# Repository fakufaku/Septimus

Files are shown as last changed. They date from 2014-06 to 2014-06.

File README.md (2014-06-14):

Septimus
========

[Septimus](https://en.wikipedia.org/wiki/Septimus_%28praenomen%29) is a driver
board to control large (2.3 inches) seven segments displays. It is designed for four
characters and has its own step-up converter to produce the large voltage
needed by the large seven segments displays.

The display is controlled by an ATtiny2313. The display is controlled through
the two-wire interface of the microcontroller.

All the components are commonly available discrete through-hole parts.

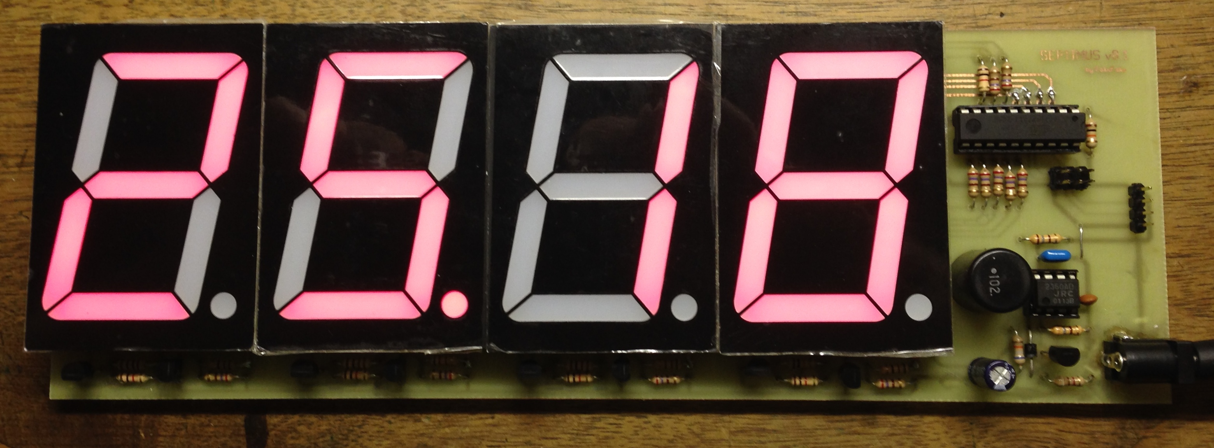
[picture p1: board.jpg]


Because of the size of the 7-segments, I couldn't use the free version of Eagle
CAD and decided to take the chance to learn its free alternative, the [gEDA suite](http://geda-project.org/).  
I found this [tutorial](http://wiki.geda-project.org/geda:gsch2pcb_tutorial)
particularly useful in my learning process. The combo of gschem/pcb is quite
powerful and has a simplicity that Eagle CAD lacks. However, the workflow to go
from schematics to PCB and keep consistency is very cumbersome and error prone.
Making custom parts is also not very practical. As a conclusion, it was a good
experience and is definitely an advantage to know an EDA without the
limitations of Eagle CAD with respect to board size and multiple layers, but I
will stick to Eagle for my simple projects.

Bill of material
----------------

* ATtiny2313 (DIP20)
* NJM2360AD Voltage regulator (drop-in replacement of [MC34063A](http://www.ti.com/litv/slls636m))
* 6x NPN transistors (C1815, ECB) (Q101, Q201, Q203, Q205, Q207, Q209)
* 4x PNP transistors (A1015, ECB) (Q202, Q204, Q206, Q208)
* 1x 1000uH coil (300mil pin spacing)
* 5x 1K resistor (R202, R206, R210, R214, R312)
* 7x 10K resistor (R201, R205, R209, R213, R301, R310, R311)
* 11x 270 resistor (R204, R208, R212, R126, R302, R303, R304, R305, R306, R307, R308)
* 4x 51 resistor (R203, R207, R211, R215)
* 3x 180 resistor (R101, R104, R309)
* 1x 9.1K resistor (R102)
* 1x 68K resistor (R103)
* 1x 10uF cap ceramic (C101)
* 1x 100uF cap electrolytic (C102)
* 1x 1nF cap ceramic (C103)
* 1x 0.1uF cap ceramic (C104)
* 1x diode (schottky, 40V)
* 1x ISP header (small footprint, 2x3 pins)
* 1x 1x4 straight pin header (100mil spacing)
* 4x 2.3inch 7-segments displays
* 1x 2.1mm barrel jack

Etch the board
--------------

The top and bottom mask files are `Septimus_mask_top.pdf` and `Septimus_mask_bot.pdf`,
respectively. The mask are mirrored so that the printed side goes directly onto the copper.
There are alignment marks and some text to avoid mistakes.

The board is double-sided and thus not trivial for home etching. However, there are only 
four tracks on the top layer and it is thus conceivable to make the PCB single layer
and manually patch it with four wires.

In addition, because of the difficulty of making metallized holes at home, a number
of jumper wires are required (7) as shown on `Septimus_info.pdf`. In the same file,
the drill bits sizes are described.

Alternatively, the gerber files are available in the folder `gerber` for sending
to a board house.

Firmware
--------

The firmware can be burnt using an ISP programmer (such as the usbtiny).

    cd firmware/
    make avrdude

If you do not use the usbtiny, edit the Makefile `PROGRAMMER` variable to
reflect the device you use.

The fuse settings are left to factory default (Low:0x64, High:0xDF, Ext:0xFF).

Arduino library
---------------

### Install

Copy `SeptimusLib/` into your local Arduino `libraries` folder. Restart
the Arduino IDE and try one of the examples.

### Example sketch.

    #include <Wire.h>
    #include <Septimus.h>

    Septimus display = Septimus(SLAVE_ADDRESS);

    unsigned int counter = 0;

    void setup() {
      display.begin();
    }

    void loop() {
      // print current counter value
      display.print(counter, DEC);
      display.writeDisplay();

      // increment and wait a second
      counter++;
      delay(1000);
    }

### Adjust brightness of display

It is possible to set the brightness of the display by using

    display.setBrightness(b)

where `b` is a value between 0 (dimmest) to 255 (brightest).

### Adjust blinking rate of display

The seven segment works by displaying each digit individually
but at high frequency so that we have the illusion of seeing
all digit lit up simultaneously. The blinking rate can be
changed using the following code. The same command can be used
to switch off the display.

    display.setRate(RATE_488Hz) // 488 Hz (default)
    display.setRate(RATE_4kHz)  // 4 kHz
    display.setRate(RATE_61Hz)  // 61 Hz
    display.setRate(RATE_STOP)  // display is off

Note that the only rate that gives smooth display and
allows for adjusting the brightness is 488 Hz, the default.

At 4kHz, the display is somewhat brighter, but only works
with brightness set to 255.

License
-------

### Schematics, PCB, firmware

(c) 2014, Robin Scheibler aka FakuFaku

    "THE BEER-WARE LICENSE" (Revision 42):
    <fakufaku@gmail.com> wrote this file. As long as you retain this notice you
    can do whatever you want with this stuff. If we meet some day, and you think
    this stuff is worth it, you can buy me a beer in return -- Robin Scheibler



With the exception of the USI TWI Slave driver code by Donald R. Blake which is GPL.

### Arduino library

The arduino library was adapted from the excellent [Adafruit LED
Backpack](https://github.com/adafruit/Adafruit-LED-Backpack-Library) library
which is released under MIT or BSD license, depending on where you look.

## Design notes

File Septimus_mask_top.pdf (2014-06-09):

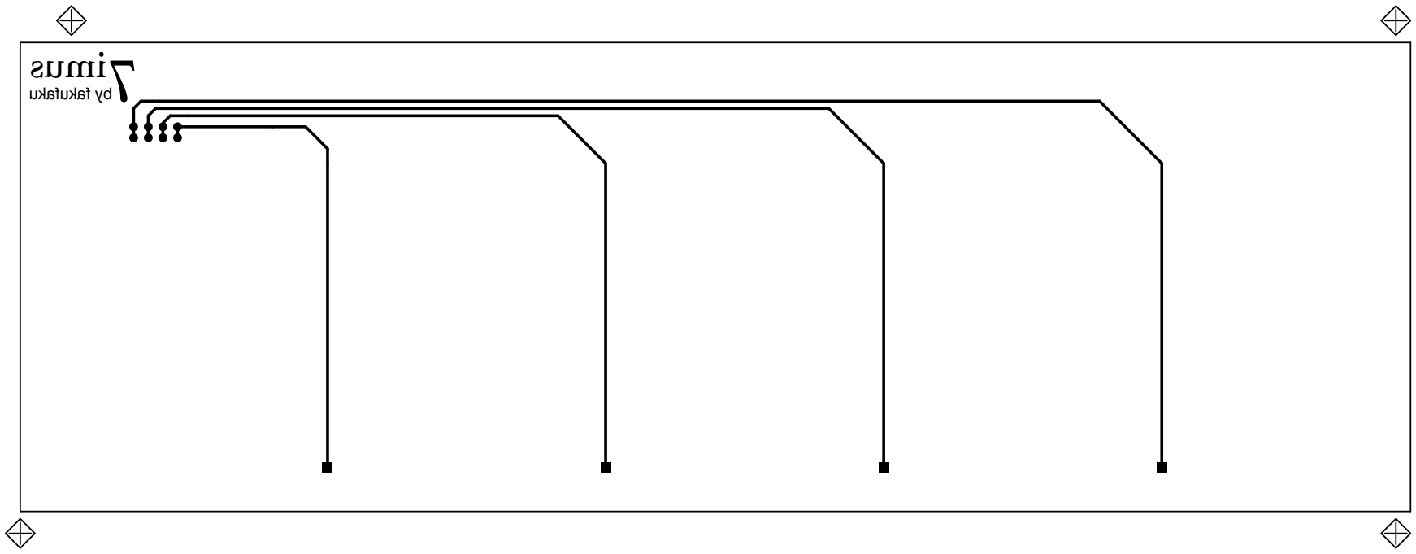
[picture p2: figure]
7imus by fakufaku

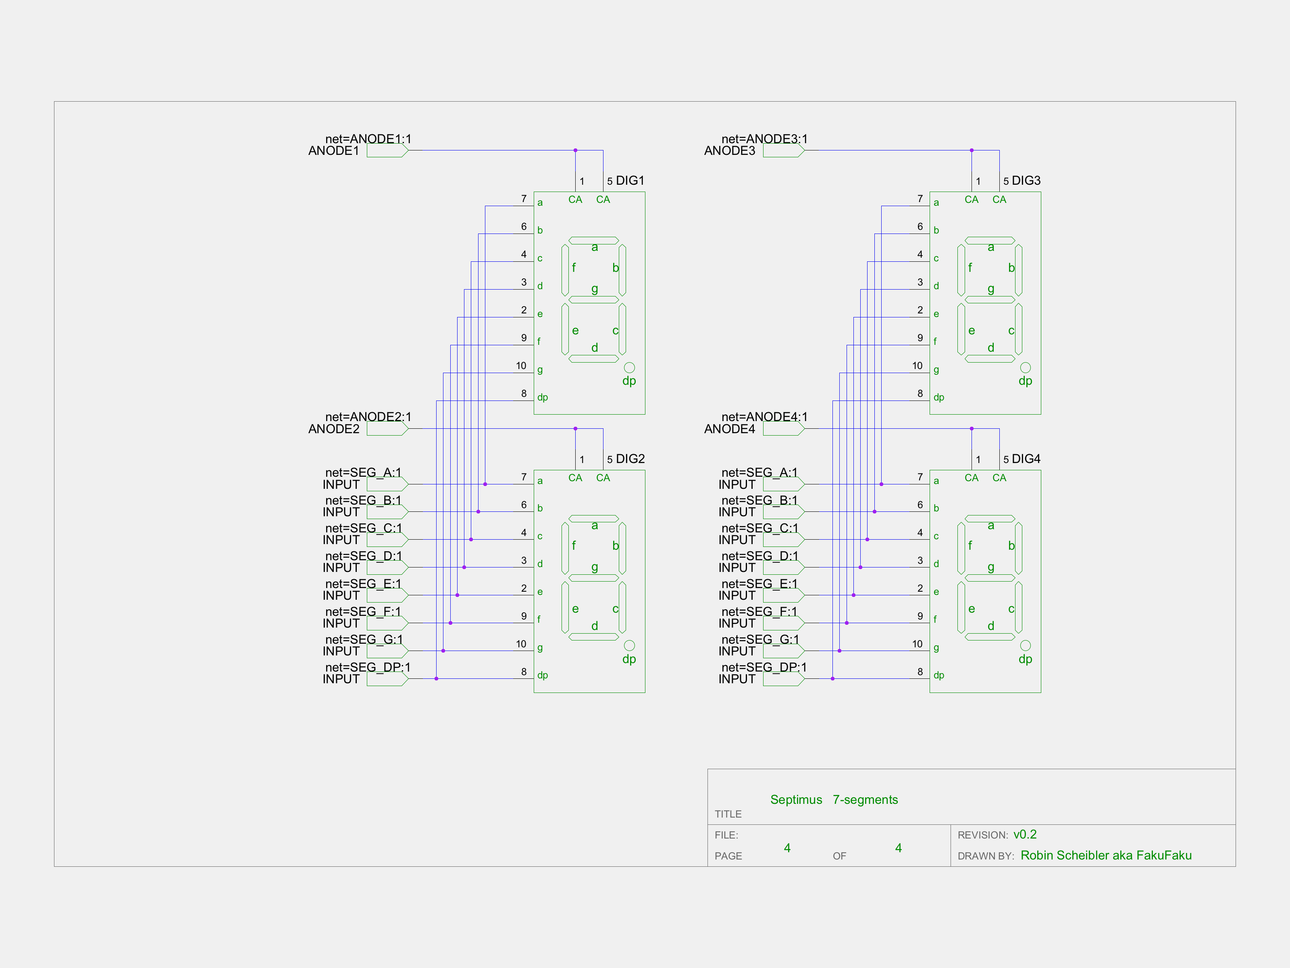
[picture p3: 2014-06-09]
schematics/Septimus_4_display.png

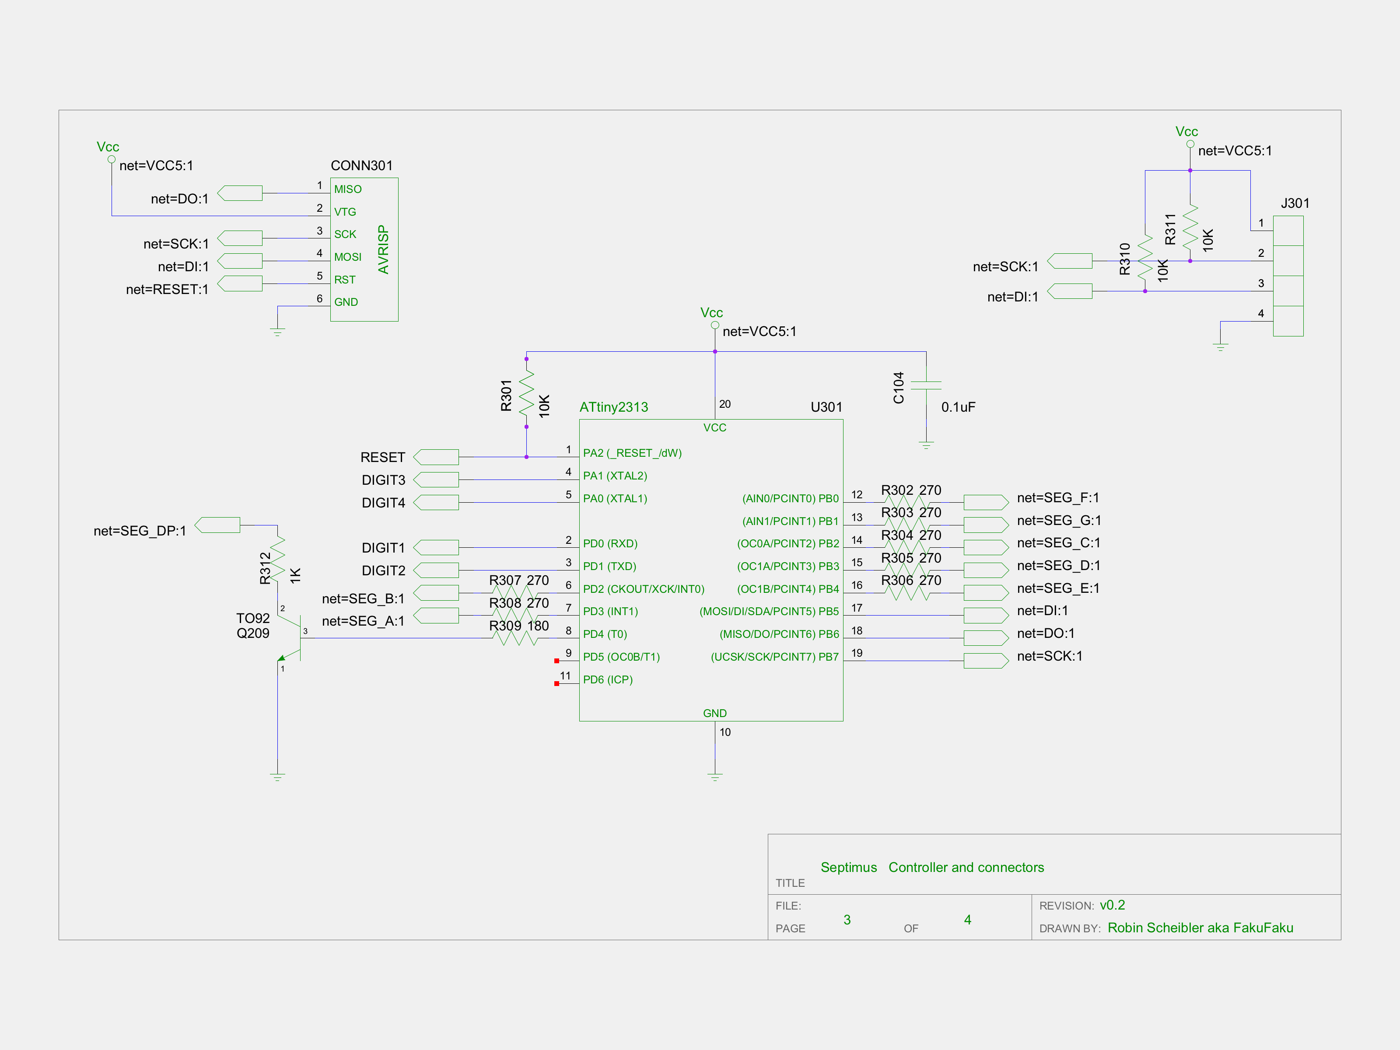
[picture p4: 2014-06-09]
schematics/Septimus_3_controller.png

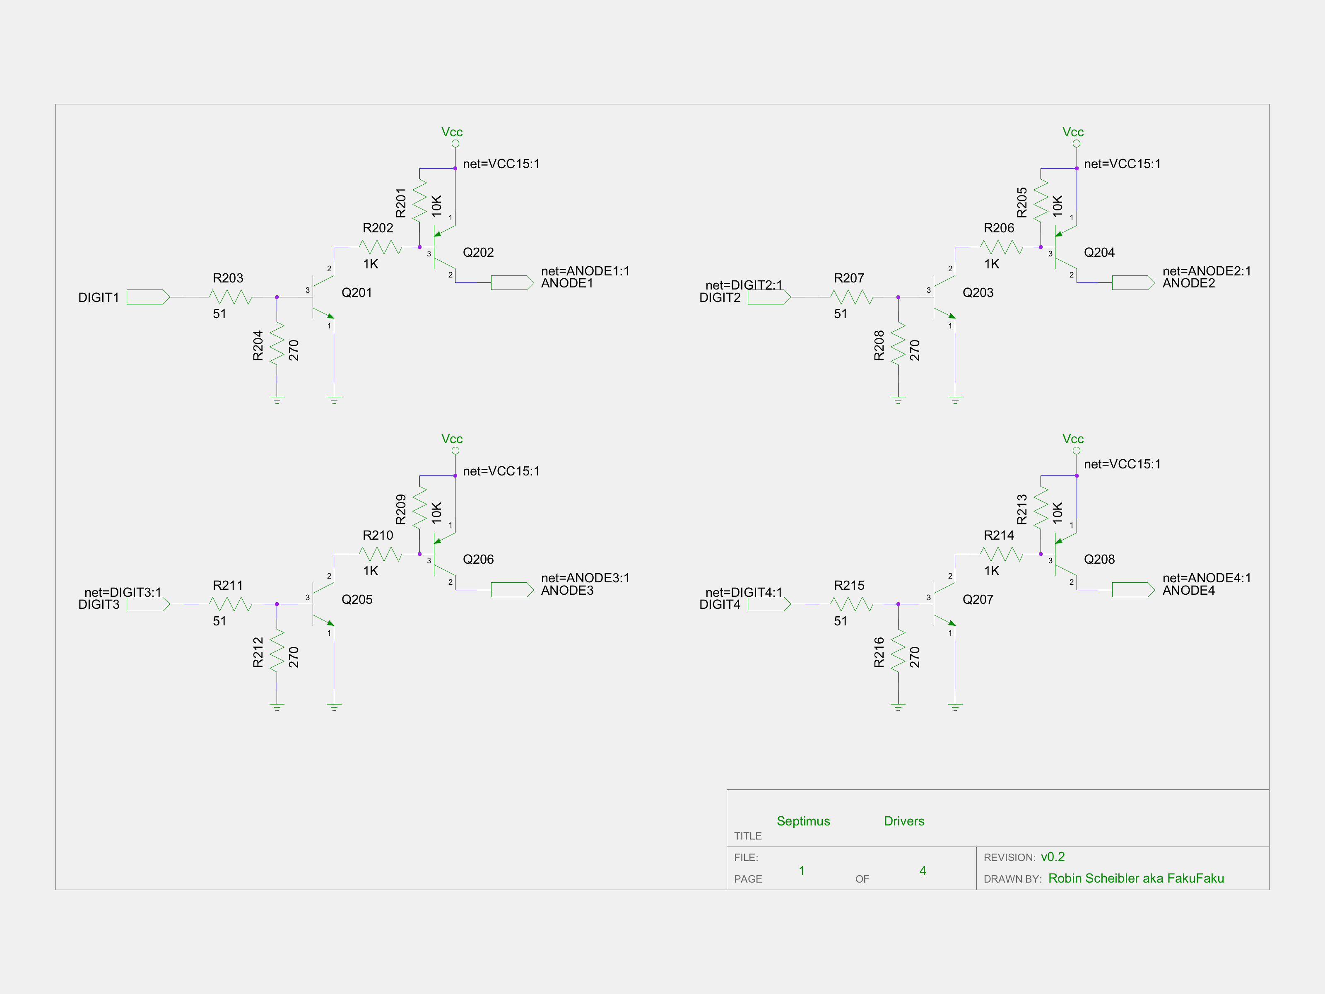
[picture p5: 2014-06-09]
schematics/Septimus_1_drivers.png

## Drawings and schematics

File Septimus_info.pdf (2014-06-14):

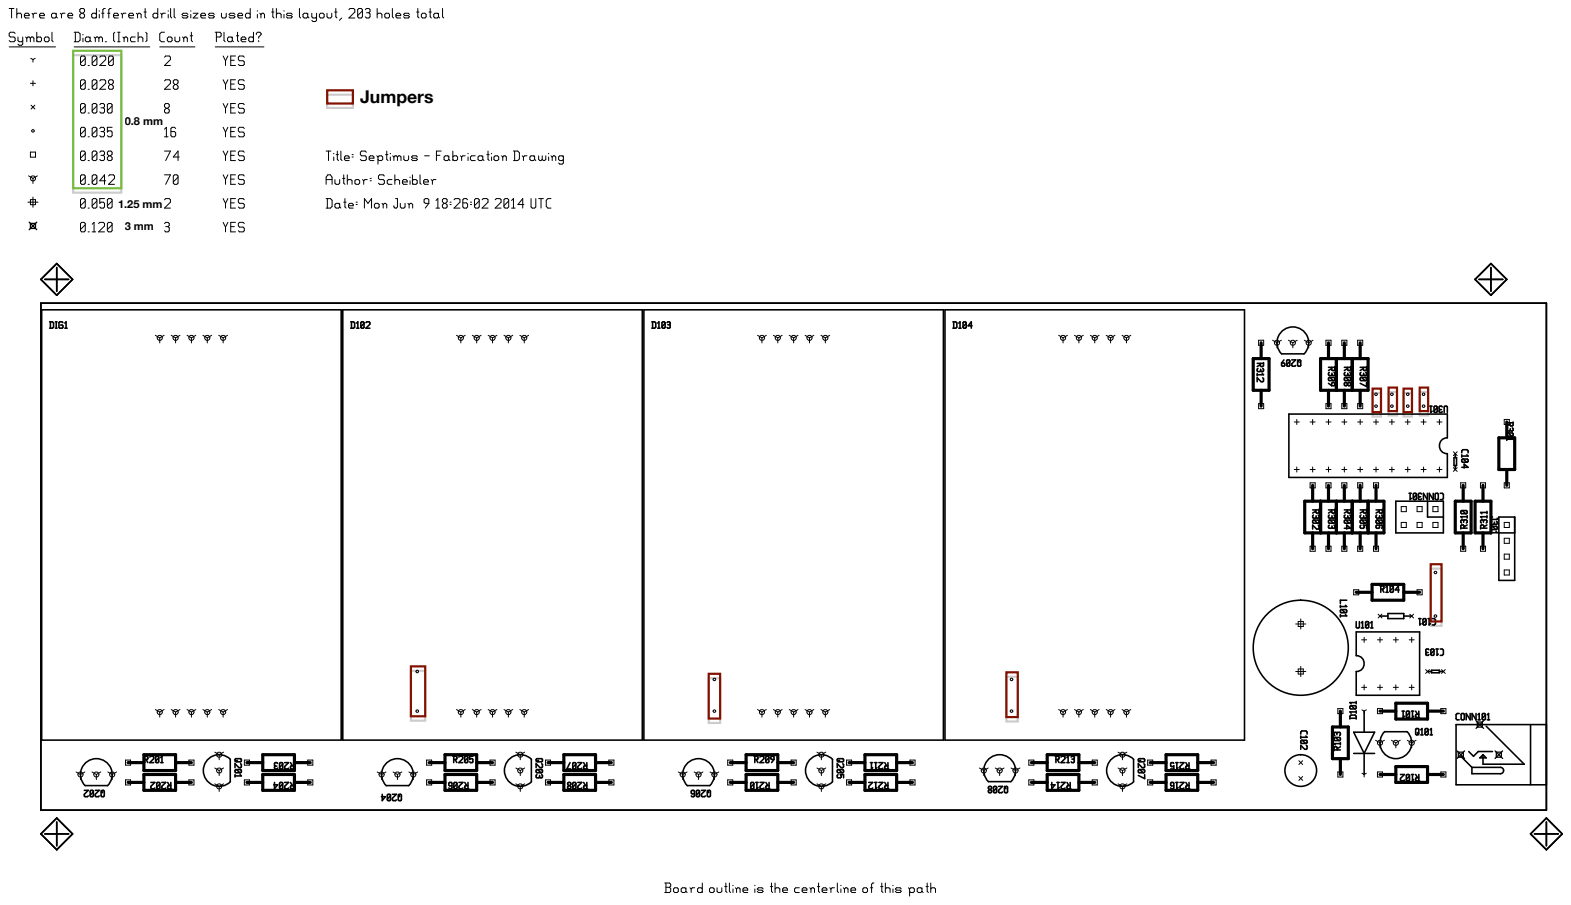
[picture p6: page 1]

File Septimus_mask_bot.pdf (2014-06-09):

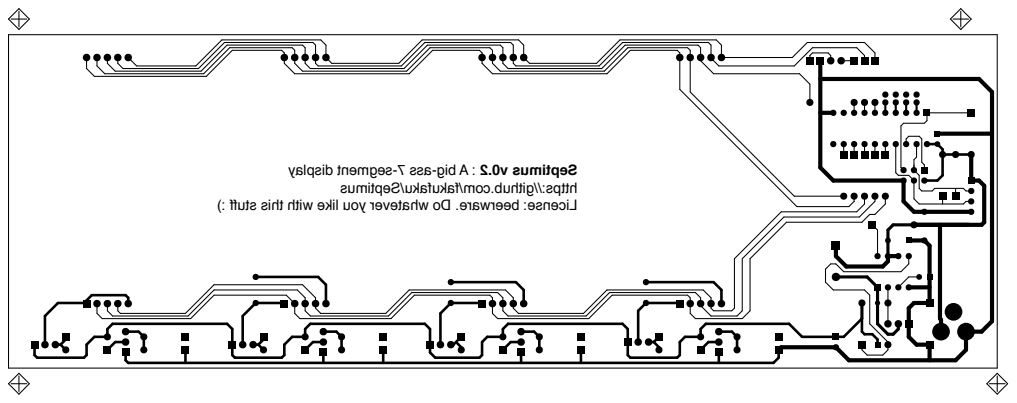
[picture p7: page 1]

: A big-ass 7-segment display Septimus v0.2

https://github.com/fakufaku/Septimus

License: beerware. Do whatever you like with this stuff :)

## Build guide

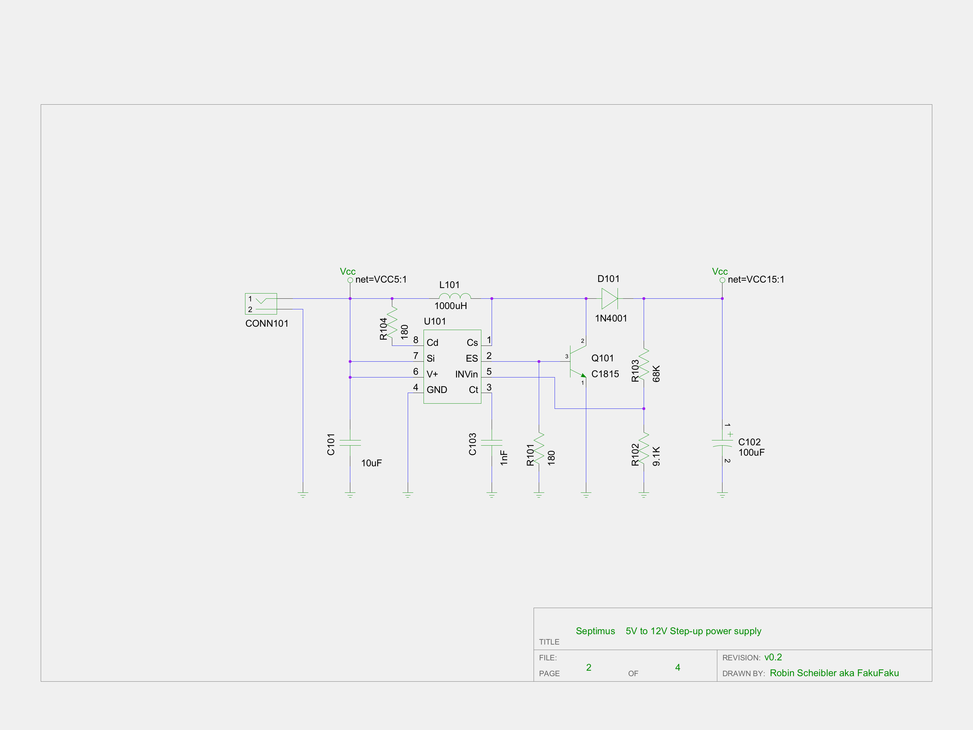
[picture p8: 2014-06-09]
schematics/Septimus_2_step-up.png

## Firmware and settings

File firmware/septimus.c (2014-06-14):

/*
* ----------------------------------------------------------------------------
* "THE BEER-WARE LICENSE" (Revision 42):
* <fakufaku@gmail.com> wrote this file. As long as you retain this notice you
* can do whatever you want with this stuff. If we meet some day, and you think
* this stuff is worth it, you can buy me a beer in return -- Robin Scheibler
* ----------------------------------------------------------------------------
*/

/*
 * This is the firmware of the Septimus big 7 segment display.
 * All code and schematics available online
 * https://github.com/fakufaku/Septimus
 */

#include <avr/sleep.h>
#include <avr/io.h>
#include <avr/interrupt.h>

#include <stdlib.h>

#include "usiTwiSlave.h"

// Allows to disable interrupt in some parts of the code
#define ENTER_CRIT()    {char volatile saved_sreg = SREG; cli()
#define LEAVE_CRIT()    SREG = saved_sreg;}

// the different timer0 frequencies
#define TIMER0_CLKDIV_4kHz (1 << CS00)
#define TIMER0_CLKDIV_488Hz (1 << CS01)
#define TIMER0_CLKDIV_61Hz (1 << CS01) | (1 << CS00)
#define TIMER0_CLKDIV_15Hz (1 << CS02)
#define TIMER0_CLKDIV_4Hz (1 << CS02) | (1 << CS00)

// The different interrupts to enable
#define SET_OCR0A_INT() TIMSK |= (1 << OCIE0A)
#define UNSET_OCR0A_INT() TIMSK &= ~(1 << OCIE0A)
#define TIMER0_STOP() TCCR0B = 0
#define TIMER0_SET_RATE(R) TCCR0B = R

#define FIRMWARE_REVISION 1
#define SLAVE_ADDRESS 50

#define DIGIT_NUMBER 4

#define DEFAULT_BRIGHTNESS 0xFE

// the bit buffer
uint8_t buffer[4] = {0x0, 0x0, 0x0, 0x0};

// we use a timer to rotate the digits
uint8_t digit_counter = 0;

// brightness register
uint8_t brightness = DEFAULT_BRIGHTNESS;

// TWI commands
#define CMD_01_SEGMENTS 0x01
#define CMD_02_BRIGHTNESS 0x02
#define CMD_03_RATE 0x03

// define the digits pins
#define DIG4_PORT PORTD
#define DIG4_DDR  DDRD
#define DIG4_PIN  0

#define DIG3_PORT PORTD
#define DIG3_DDR  DDRD
#define DIG3_PIN  1

#define DIG2_PORT PORTA
#define DIG2_DDR  DDRA
#define DIG2_PIN  1

#define DIG1_PORT PORTA
#define DIG1_DDR  DDRA
#define DIG1_PIN  0

// define the segments pins
#define SEG_A_PORT PORTD
#define SEG_A_DDR  DDRD
#define SEG_A_PIN  3

#define SEG_B_PORT PORTD
#define SEG_B_DDR  DDRD
#define SEG_B_PIN  2

#define SEG_C_PORT PORTB
#define SEG_C_DDR  DDRB
#define SEG_C_PIN  2

#define SEG_D_PORT PORTB
#define SEG_D_DDR  DDRB
#define SEG_D_PIN  3

#define SEG_E_PORT PORTB
#define SEG_E_DDR  DDRB
#define SEG_E_PIN  4

#define SEG_F_PORT PORTB
#define SEG_F_DDR  DDRB
#define SEG_F_PIN  0

#define SEG_G_PORT PORTB
#define SEG_G_DDR  DDRB
#define SEG_G_PIN  1

#define SEG_DP_PORT PORTD
#define SEG_DP_DDR  DDRD
#define SEG_DP_PIN  4

// turn off all digits
void digits_all_off(void)
{
  DIG1_PORT &= ~_BV(DIG1_PIN);
  DIG2_PORT &= ~_BV(DIG2_PIN);
  DIG3_PORT &= ~_BV(DIG3_PIN);
  DIG4_PORT &= ~_BV(DIG4_PIN);
}

// light up a digit
void light_digit(uint8_t n)
{
  switch (n)
  {
    case 1:
      DIG1_PORT |= _BV(DIG1_PIN);
      break;

    case 2:
      DIG2_PORT |= _BV(DIG2_PIN);
      break;

    case 3:
      DIG3_PORT |= _BV(DIG3_PIN);
      break;

    case 4:
      DIG4_PORT |= _BV(DIG4_PIN);
      break;

    default:
      digits_all_off();
  }
}

// set the segments for a given number
void set_segments(uint8_t bits)
{
  //A
  if (bits & 0x1)
    SEG_A_DDR |= _BV(SEG_A_PIN);
  else
    SEG_A_DDR &= ~_BV(SEG_A_PIN);
  //B
  if (bits & 0x2)
    SEG_B_DDR |= _BV(SEG_B_PIN);
  else
    SEG_B_DDR &= ~_BV(SEG_B_PIN);
  //C
  if (bits & 0x4)
    SEG_C_DDR |= _BV(SEG_C_PIN);
  else
    SEG_C_DDR &= ~_BV(SEG_C_PIN);
  //D
  if (bits & 0x8)
    SEG_D_DDR |= _BV(SEG_D_PIN);
  else
    SEG_D_DDR &= ~_BV(SEG_D_PIN);
  //E
  if (bits & 0x10)
    SEG_E_DDR |= _BV(SEG_E_PIN);
  else
    SEG_E_DDR &= ~_BV(SEG_E_PIN);
  //F
  if (bits & 0x20)
    SEG_F_DDR |= _BV(SEG_F_PIN);
  else
    SEG_F_DDR &= ~_BV(SEG_F_PIN);
  //G
  if (bits & 0x40)
    SEG_G_DDR |= _BV(SEG_G_PIN);
  else
    SEG_G_DDR &= ~_BV(SEG_G_PIN);
  //DP
  if (bits & 0x80)
  {
    SEG_DP_DDR |= _BV(SEG_DP_PIN);
    SEG_DP_PORT |= _BV(SEG_DP_PIN);
  }
  else
  {
    SEG_DP_DDR |= _BV(SEG_DP_PIN);
    SEG_DP_PORT &= ~_BV(SEG_DP_PIN);
  }
}

// process the TWI command
void processTWI( void )
{
  uint8_t b,c;

  // receive the command
  b = usiTwiReceiveByte();

  switch (b) {
    case CMD_01_SEGMENTS: // save brightness
      // receive the 4 digits
      for (c = 0 ; c < DIGIT_NUMBER ; c++)
        buffer[c] = usiTwiReceiveByte();
      break;

    case CMD_02_BRIGHTNESS:
      // receive the brightness byte
      brightness = usiTwiReceiveByte();  // update the output compare A with new value
      if (brightness == 0xFF)
        UNSET_OCR0A_INT();
      else
        SET_OCR0A_INT();
      break;

    case CMD_03_RATE:
      c = usiTwiReceiveByte();
      switch (c)
      {
        case 0x00:
          TIMER0_STOP();
          break;

        case 0x01:
          TIMER0_SET_RATE(TIMER0_CLKDIV_4kHz);
          break;

        case 0x02:
          TIMER0_SET_RATE(TIMER0_CLKDIV_488Hz);
          break;

        case 0x03:
          TIMER0_SET_RATE(TIMER0_CLKDIV_61Hz);
          break;
      }
      break;

    default:
      // nothing to do
      break;
  }
}

// The output compare A interrupt to turn off the digit
SIGNAL(TIMER0_COMPA_vect)
{
  ENTER_CRIT();

  // turn off all digits
  digits_all_off();

  LEAVE_CRIT();
}

// The timer overflow interrupt routine
SIGNAL(TIMER0_OVF_vect)
{
  ENTER_CRIT();

  // turn off all digits
  digits_all_off();

  // increment the digit to display
  digit_counter = (digit_counter+1) % DIGIT_NUMBER;

  // set the segments
  set_segments(buffer[digit_counter]);

  // turn digit on
  light_digit(digit_counter+1);

  // set the time the digit should light up
  OCR0A = brightness;

  LEAVE_CRIT();
}

int main()
{
  // set digits as output and disable them all
  DIG1_DDR |= _BV(DIG1_PIN);
  DIG2_DDR |= _BV(DIG2_PIN);
  DIG3_DDR |= _BV(DIG3_PIN);
  DIG4_DDR |= _BV(DIG4_PIN);
  light_digit(0);

  // setup all segments as inputs and low
  SEG_A_DDR &= ~_BV(SEG_A_PIN);
  SEG_B_DDR &= ~_BV(SEG_B_PIN);
  SEG_C_DDR &= ~_BV(SEG_C_PIN);
  SEG_D_DDR &= ~_BV(SEG_D_PIN);
  SEG_E_DDR &= ~_BV(SEG_E_PIN);
  SEG_F_DDR &= ~_BV(SEG_F_PIN);
  SEG_G_DDR &= ~_BV(SEG_G_PIN);
  
  SEG_A_PORT &= ~_BV(SEG_A_PIN);
  SEG_B_PORT &= ~_BV(SEG_B_PIN);
  SEG_C_PORT &= ~_BV(SEG_C_PIN);
  SEG_D_PORT &= ~_BV(SEG_D_PIN);
  SEG_E_PORT &= ~_BV(SEG_E_PIN);
  SEG_F_PORT &= ~_BV(SEG_F_PIN);
  SEG_G_PORT &= ~_BV(SEG_G_PIN);

  // set DP as output and to ground
  SEG_DP_DDR |= _BV(SEG_DP_PIN);
  SEG_DP_PORT &= ~_BV(SEG_DP_PIN);

  // set up timer 1 as system clock
  TIMSK = (1 << TOIE0);         // overflow interrupts
  TCCR0B = TIMER0_CLKDIV_488Hz; // default blink rate at 488Hz

  
  // init the TWI slave
  usiTwiSlaveInit(SLAVE_ADDRESS);

  // enable interrupts
  sei();

  // The infinite loop
  while (1)
  {
    // process Twi commands
    while (usiTwiDataInReceiveBuffer())
    {
      processTWI();
    }
  }

}

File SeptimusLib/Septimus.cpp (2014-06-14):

/***************************************************
 * This is the library for I2C big 7 segment display 'Septimus'
 *
 * This library was adapted from adafruit's i2c matrix led backpack
 * library. It was slimmed down and adapted to work with this
 * custom 7 segment back pack 'Septimus'
 * ----> https://github.com/fakufaku/Septimus
 *
 * Septimus uses I2C to communicate, 2 pins are required to interface. 
 * The I2C address of the display is 50 (decimal)
 *
 * Originally written by Limor Fried/Ladyada for Adafruit Industries.
 * Adapted for Septimus by Robin Scheibler/fakufaku
 * BSD license, all text above must be included in any redistribution
 * ****************************************************/

#ifdef __AVR_ATtiny85__
#include <TinyWireM.h>
#define Wire TinyWireM
#else
#include <Wire.h>
#endif

#include "Septimus.h"

static const uint8_t numbertable[] = {
  0x3F, /* 0 */
  0x06, /* 1 */
  0x5B, /* 2 */
  0x4F, /* 3 */
  0x66, /* 4 */
  0x6D, /* 5 */
  0x7D, /* 6 */
  0x07, /* 7 */
  0x7F, /* 8 */
  0x6F, /* 9 */
  0x77, /* a */
  0x7C, /* b */
  0x39, /* C */
  0x5E, /* d */
  0x79, /* E */
  0x71, /* F */
};

void Septimus::setBrightness(uint8_t b) 
{
  Wire.beginTransmission(i2c_addr);
  Wire.write(CMD_02_BRIGHTNESS);
  Wire.write(b);
  Wire.endTransmission();
}

Septimus::Septimus(uint8_t _addr = SLAVE_ADDRESS) 
{
  i2c_addr = _addr;
  position = 0;
}

void Septimus::begin(void)
{
  Wire.begin();
  setRate(RATE_488Hz);
  setBrightness(255);
}

void Septimus::writeDisplay(void) 
{
  Wire.beginTransmission(i2c_addr);
  Wire.write(CMD_01_SEGMENTS);
  for (uint8_t i = 0; i < DIGIT_NUMBER; i++)
  {
    Wire.write(displaybuffer[DIGIT_NUMBER-i-1]);
  }
  Wire.endTransmission();
}

void Septimus::setRate(uint8_t r)
{
  Wire.beginTransmission(i2c_addr);
  Wire.write(CMD_03_RATE);
  uint8_t v = Wire.write(r);
  Wire.endTransmission();
}

void Septimus::clear(void) 
{
  for (uint8_t i = 0; i < DIGIT_NUMBER; i++) {
    displaybuffer[i] = 0;
  }
}

void Septimus::print(unsigned long n, int base)
{
  if (base == 0) write(n);
  else printNumber(n, base);
}

void Septimus::print(char c, int base)
{
  print((long) c, base);
}

void Septimus::print(unsigned char b, int base)
{
  print((unsigned long) b, base);
}

void Septimus::print(int n, int base)
{
  print((long) n, base);
}

void Septimus::print(unsigned int n, int base)
{
  print((unsigned long) n, base);
}

void Septimus::println(void) 
{
  position = 0;
}

void Septimus::println(char c, int base)
{
  print(c, base);
  println();
}

void Septimus::println(unsigned char b, int base)
{
  print(b, base);
  println();
}

void Septimus::println(int n, int base)
{
  print(n, base);
  println();
}

void Septimus::println(unsigned int n, int base)
{
  print(n, base);
  println();
}

void Septimus::println(long n, int base)
{
  print(n, base);
  println();
}

void Septimus::println(unsigned long n, int base)
{
  print(n, base);
  println();
}

void Septimus::println(double n, int digits)
{
  print(n, digits);
  println();
}

void Septimus::print(double n, int digits)
{
  printFloat(n, digits);
}


size_t Septimus::write(uint8_t c) 
{

  uint8_t r = 0;

  if (c == '\n') position = 0;
  if (c == '\r') position = 0;

  if ((c >= '0') && (c <= '9')) {
    writeDigitNum(position, c-'0');
    r = 1;
  }

  position++;

  return r;
}

void Septimus::writeDigitRaw(uint8_t d, uint8_t bitmask) 
{
  if (d >= 4) return;
  displaybuffer[d] = bitmask;
}

void Septimus::writeDigitNum(uint8_t d, uint8_t num, boolean dot) 
{
  if (d >= 4) return;

  writeDigitRaw(d, numbertable[num] | (dot << 7));
}

void Septimus::print(long n, int base)
{
  printNumber(n, base);
}

void Septimus::printNumber(long n, uint8_t base)
{
  printFloat(n, 0, base);
}

void Septimus::printFloat(double n, uint8_t fracDigits, uint8_t base)
{
  uint8_t numericDigits = 4; // available digits on display
  boolean isNegative = false; // true if the number is negative

  // is the number negative?
  if(n < 0) 
  {
    isNegative = true; // need to draw sign later
    --numericDigits; // the sign will take up one digit
    n *= -1; // pretend the number is positive
  }

  // calculate the factor required to shift all fractional digits
  // into the integer part of the number
  double toIntFactor = 1.0;
  for(int i = 0; i < fracDigits; ++i) toIntFactor *= base;

  // create integer containing digits to display by applying
  // shifting factor and rounding adjustment
  uint32_t displayNumber = n * toIntFactor + 0.5;

  // calculate upper bound on displayNumber given
  // available digits on display
  uint32_t tooBig = 1;
  for(int i = 0; i < numericDigits; ++i) tooBig *= base;

  // if displayNumber is too large, try fewer fractional digits
  while(displayNumber >= tooBig) 
  {
    --fracDigits;
    toIntFactor /= base;
    displayNumber = n * toIntFactor + 0.5;
  }

  // did toIntFactor shift the decimal off the display?
  if (toIntFactor < 1) 
  {
    printError();
  } 
  else 
  {
    // otherwise, display the number
    int8_t displayPos = 3;

    if (displayNumber) //if displayNumber is not 0
    {
      for(uint8_t i = 0; displayNumber; ++i) 
      {
        boolean displayDecimal = (fracDigits != 0 && i == fracDigits);
        writeDigitNum(displayPos--, displayNumber % base, displayDecimal);
        displayNumber /= base;
      }
    }
    else 
    {
      writeDigitNum(displayPos--, 0, false);
    }

    // display negative sign if negative
    if(isNegative) writeDigitRaw(displayPos--, 0x40);

    // clear remaining display positions
    while(displayPos >= 0) writeDigitRaw(displayPos--, 0x00);
  }
}

void Septimus::printError(void) {
  uint8_t E = numbertable[14]; // upper case 'E'
  uint8_t r = 0x50; // lower case 'r'
  writeDigitRaw(0, E); // 'E'
  writeDigitRaw(1, r); // 'r'
  writeDigitRaw(2, r | 0x80);  // 'r.'
  writeDigitRaw(3, 0); // nothing
}

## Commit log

2014-06-09 Images of board and schematics.
2014-06-14 Display can now communicate using TWI (I2C). README expanded.
